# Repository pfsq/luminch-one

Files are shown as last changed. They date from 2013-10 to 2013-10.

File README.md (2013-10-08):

Luminch One
===========

Luminch One is an interactive lamp controlled by the movements of your hand.
Wave your hand over it to turn it on or off, or move your hand up or down
above it to change its brightness. Inside the lamp, an Arduino hooked to an
infrared distance sensor tracks your hand and sets the state and the
brightness of the LED lamp.

Copyright 2012 by [Francisco Castro](http://fran.cc)

EAGLE files, copyleft (ɔ) 2013 by [Pablo Fernández](http://theansweris27.wordpress.com)

[More info...](http://fran.cc/post/15139791161/luminch-one)

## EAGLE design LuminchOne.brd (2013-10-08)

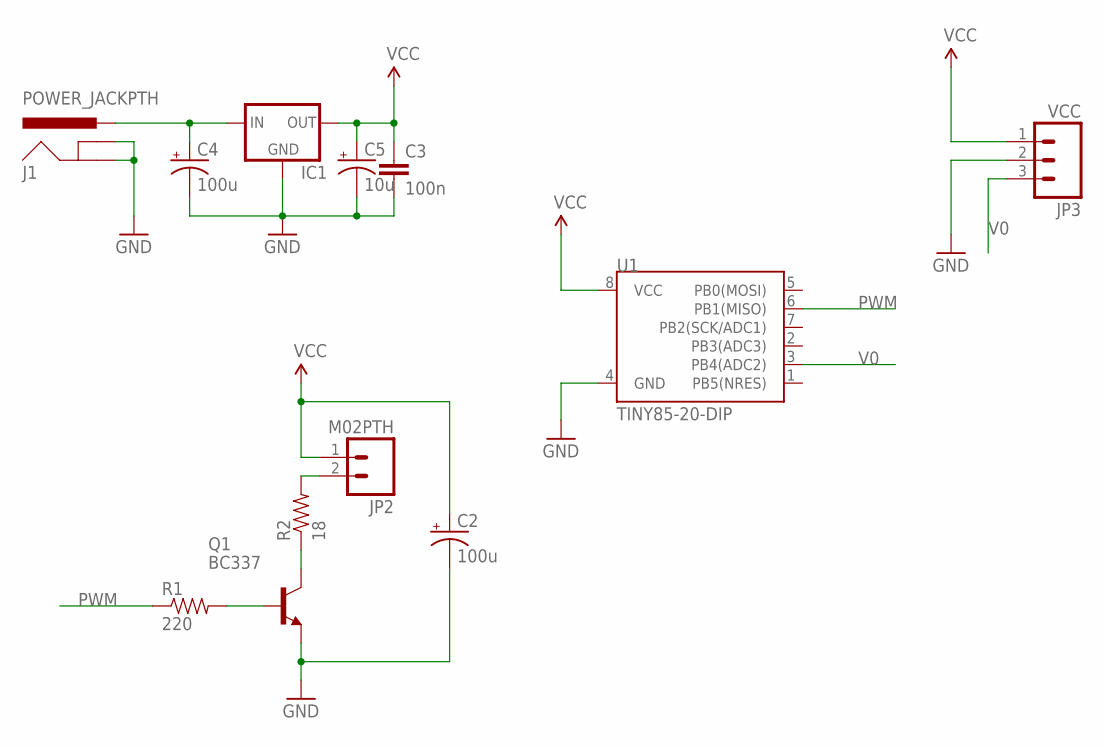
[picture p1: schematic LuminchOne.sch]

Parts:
C2, C4: 100u; CPOL-RADIAL-100UF-25V
C3: 100n; CAP-PTH-SMALL
C5: 10u; CPOL-RADIAL-10UF-25V
IC1: V_REG_78XX-TO-220; TO-220-ALT
J1: POWER_JACKPTH; POWER_JACK_PTH
JP2: M02PTH; 1X02
JP3: VCC; 1X03
Q1: BC337; TO92
R1: 220; AXIAL-0.4
R2: 18; AXIAL-0.6
U1: TINY85-20-DIP; DIP08

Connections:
GND: C2.2 (-), C3.2, C4.2 (-), C5.2 (-), IC1.GND, J1.GND, J1.GNDBREAK, JP3.2, Q1.1 (E), U1.4 (GND)
unnamed: Q1.2 (B), R1.P$2 (2)
unnamed: JP2.2, R2.P$2 (2)
unnamed: C4.1 (+), IC1.IN, J1.PWR
unnamed: Q1.3 (C), R2.P$1 (1)
PWM: R1.P$1 (1), U1.6 (PB1(MISO))
V0: JP3.3, U1.3 (PB4(ADC2))
VCC: C2.1 (+), C3.1, C5.1 (+), IC1.OUT, JP2.1, JP3.1, U1.8 (VCC)

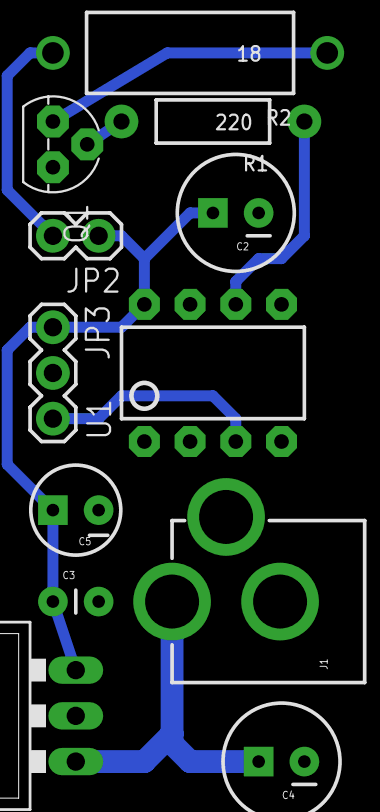
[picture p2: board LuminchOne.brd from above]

Board: 2 copper layers, 12 parts (0 on the bottom side), 8 nets.

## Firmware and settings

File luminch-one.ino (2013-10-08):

//  Luminch One - Copyright 2012 by Francisco Castro <http://fran.cc>
//
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
#define LED_PIN 1
#define SENSOR_PIN A2

#define SENSE_THRESHOLD 150
#define TRACK_THRESHOLD 230
#define DEBOUNCE_CYCLES 30
#define START_TRACKING_CYCLES 180
#define END_TRACKING_CYCLES 210
#define HAND_MINIMUM_CHANGE 15

int adc_input = 0;
int pwm_output = 0;
int stored_bright = 0xFF;
int target_bright = 0;
int hand_tracked_bright = 0;

boolean lamp_lighted = false;
boolean hand_tracking = false;

unsigned char hand_cycles = 0;
unsigned char debounce_cycles = 0;

int sample_1 = 0;
int sample_2 = 0;
int sample_3 = 0;
int sample_4 = 0;


void setup()  {
  analogWrite(LED_PIN, 0);
} 

void loop()  {
  sample_1 = analogRead(SENSOR_PIN); delay(1);
  sample_2 = analogRead(SENSOR_PIN); delay(1);
  sample_3 = analogRead(SENSOR_PIN); delay(1);
  sample_4 = analogRead(SENSOR_PIN); delay(1);
  adc_input = (sample_1 + sample_2 + sample_3 + sample_4) >> 2;

  if(debounce_cycles)
    debounce_cycles -= 1;
  else {
    if(hand_tracking) {
      if(adc_input > SENSE_THRESHOLD) {        
        if(adc_input > TRACK_THRESHOLD + 0xFF)
          hand_tracked_bright = 0;
        else if(adc_input < TRACK_THRESHOLD)
          hand_tracked_bright = 0xff;
        else
          hand_tracked_bright = 0xFF - (adc_input - TRACK_THRESHOLD);

        if(abs(target_bright - hand_tracked_bright) > HAND_MINIMUM_CHANGE || !lamp_lighted) {
          target_bright = (target_bright + (hand_tracked_bright > 8 ? hand_tracked_bright : 8)) >> 1;
          lamp_lighted = true;
        }
        hand_cycles = 0;
      }
      else {
        target_bright = pwm_output;
        stored_bright = pwm_output;
        hand_cycles += 1;
        if(hand_cycles == END_TRACKING_CYCLES) {
          hand_tracking = false;
          hand_cycles = 0;
        }
      }      
    }
    else {
      if(adc_input > SENSE_THRESHOLD) {
        hand_cycles += 1;
        if(hand_cycles == START_TRACKING_CYCLES) {
          hand_tracking = true;
          hand_cycles = 0;
        }
      }
      else {
        if(hand_cycles) {
          lamp_lighted = !lamp_lighted;
          target_bright = lamp_lighted ? stored_bright : 0;
          debounce_cycles = DEBOUNCE_CYCLES;
        }
        hand_cycles = 0;
      }
    }
  }
  
  if(pwm_output != target_bright) {
    if(pwm_output > target_bright && pwm_output > 0) --pwm_output;
    if(pwm_output < target_bright && pwm_output < 0xFF) ++pwm_output;
    analogWrite(LED_PIN, pwm_output);
    delay((0xFF - abs(target_bright - pwm_output)) >> 5);
  }
}

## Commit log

2013-10-05 Deletion
    Files not needed for the ATtiny85 project
    [luminch_one.fz]
2013-10-05 EAGLE Files
    [LuminchOne.brd, LuminchOne.sch]
2013-10-08 update luminch-one.ino
    New pin definitions for ATtiny 85

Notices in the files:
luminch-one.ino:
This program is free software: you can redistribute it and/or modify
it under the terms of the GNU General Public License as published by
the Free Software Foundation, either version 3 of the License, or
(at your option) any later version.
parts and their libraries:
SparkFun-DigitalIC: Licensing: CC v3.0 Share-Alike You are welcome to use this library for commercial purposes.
